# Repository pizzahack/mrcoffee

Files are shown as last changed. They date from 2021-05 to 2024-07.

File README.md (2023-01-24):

# MR. COFFEE - robotic arm

||

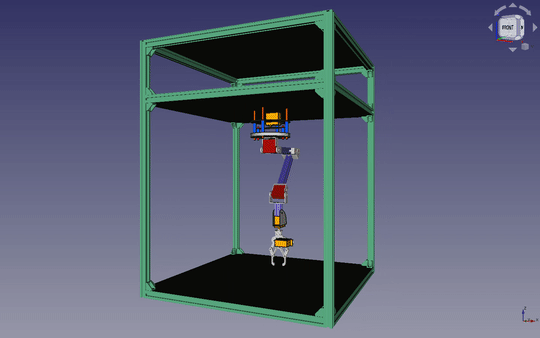
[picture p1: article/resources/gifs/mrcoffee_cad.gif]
||

## Table of contents

* [General info](#general-info)
* [Build thread on Twitter](#build-thread-on-twitter)
* [Technologies](#technologies)
* [Hardware](#hardware)
* [Build Log](#build-log)

## General info

MR. COFFEE will be a internet connected chess-playing robot. It'll allow users to play in human-machine mode (my custom UCI engine) or human-human mode, where robot serves as a remote hand for connected player. Build thread on twitter is a simple tech blog. After release of final verison of robot, I'll write an article and post full codebase. 

## Build thread on Twitter

<html lang="en">

<blockquote class="twitter-tweet"><p lang="en" dir="ltr"><a href="https://twitter.com/hashtag/robotics?src=hash&amp;ref_src=twsrc%5Etfw">#robotics</a><br>There is some sort of special feeling when you combine hardware with software and it starts to move. <a href="https://t.co/OUUlQEHs6o">pic.twitter.com/OUUlQEHs6o</a></p>&mdash; Kamil Kurach (@kamil_kurach) <a href="https://twitter.com/kamil_kurach/status/1475853391540723722?ref_src=twsrc%5Etfw">December 28, 2021</a></blockquote> <script async src="https://platform.twitter.com/widgets.js" charset="utf-8"></script>

</html>
 
## Technologies

## Hardware

## Build Log

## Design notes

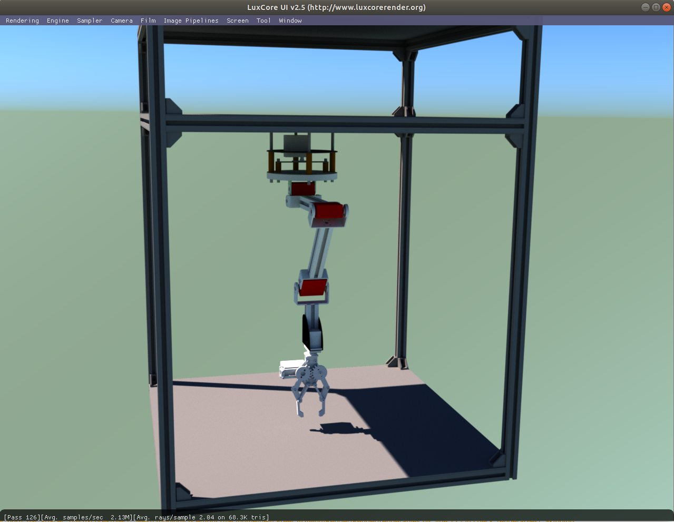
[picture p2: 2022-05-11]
mrcoffee.png

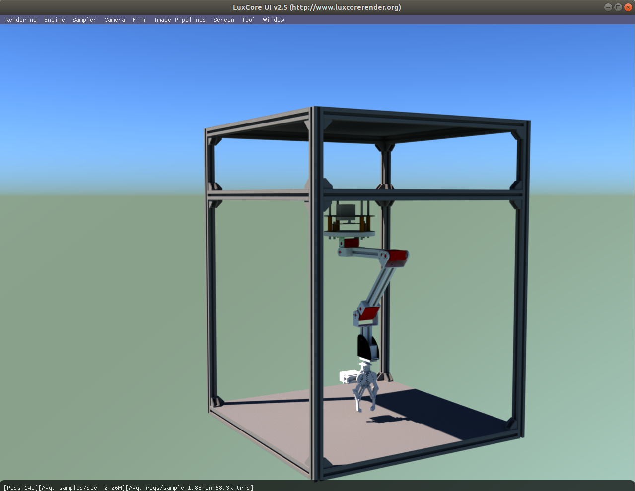
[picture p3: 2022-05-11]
mrcoffee2.png

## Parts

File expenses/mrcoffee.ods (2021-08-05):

PART_NAME | STATUS | MANUFACTURER / SUPPLIER | MANUFACTURER_PRODUCT_ID | O_PRICE | PRICE_PLN | QUANTITY | TOTAL_PLN | PART_TYPE | PART_MATERIAL | STL_FILENAME
ALU_500MM_BLACK |  | Aluxprofiel KM Engineering | 2020-BLACK | 13,68 zł |  | 10 |  | NON ELECTRONIC | ALUMINIUM
ALU_700MM_BLACK |  | Aluxprofiel KM Engineering | 2020-BLACK | 19,15 zł |  | 4 |  | NON ELECTRONIC | ALUMINIUM
ALU_600MM_SILVER |  | Aluxprofiel KM Engineering | 2020 | 13,02 zł |  | 1 |  | NON ELECTRONIC
SIDE_PLATE |  | CUSTOM |  |  |  | 2 |  | NON ELECTRONIC | METAL
FRONT_PLATE |  | CUSTOM |  |  |  | 1 |  | NON ELECTRONIC | METAL
BACK_PLATE |  | CUSTOM |  |  |  | 1 |  | NON ELECTRONIC | METAL
ELECTRIC_SOCKET |  |  |  |  |  | 1 |  | ELECTRONIC | PLASTIC/METAL
ON/OFF BUTTON |  |  |  |  |  | 1 |  | ELECTRONIC | PLASTIC/METAL
220V_CABLE |  |  |  |  |  | 1 |  | ELECTRONIC | PLASTIC/METAL
BLACK_PLEXIGLASS_TOP |  |  |  |  |  | 1 |  | NON ELECTRONIC | PLASTIC
BLACK_PLEXIGLASS_BOTTOM |  |  |  |  |  | 1 |  | NON ELECTRONIC | PLASTIC
CLEAR_PLEXIGLASS_SIDES |  |  |  |  |  | 4 |  | NON ELECTRONIC | PLASTIC
M6_BOLT |  |  |  |  |  | 32 |  | NON ELECTRONIC
M6_WASHER |  |  |  |  |  | 32 |  | NON ELECTRONIC
M6_NUT |  |  |  |  |  | 32 |  | NON ELECTRONIC
90_BRACKET |  | ABC-RC | 14416 | 2,90 zł |  | 32
M6_SLOT |  |  |  |  |  | 16
2020_ENDCAP_10_PACK |  | ABC-RC | 15877 | 3,9 |  | 1 |  | NON ELECTRONIC
SERVO_270_20KG |  | FEICHAO | F40451-270 | $13,08 |  | 3 |  | ELECTRONIC | PLASTIC/METAL
SERVO_360_11KG |  | n/a | MG996R | $5,59 |  | 1 |  | ELECTRONIC | PLASTIC/METAL
BEARING_360 |  | n/a | n/a | $8,48 |  | 1 |  | NON ELECTRONIC | ALUMINIUM
SERVO_SMALL_BRACKET |  | FEICHAO | n/a | included |  | 3 |  | NON ELECTRONIC | ALUMINIUM
SERVO_LARGE_BRACKET |  | FEICHAO | n/a | included |  | 3 |  | NON ELECTRONIC | ALUMINIUM
SERVO_METAL_DISC |  | FEICHAO | n/a | included |  | 3 |  | NON ELECTRONIC | ALUMINIUM
SERVO_METAL_DISC_W_GEAR |  | FEICHAO | n/a | included |  | 3 |  | NON ELECTRONIC | ALUMINIUM
LINK_1 |  | CUSTOM |  |  |  | 1 |  | NON ELECTRONIC | ALUMINIUM
LINK_2 |  | CUSTOM |  |  |  | 1 |  | NON ELECTRONIC | ALUMINIUM
LINK_3 |  | CUSTOM |  |  |  | 1 |  | NON ELECTRONIC | ALUMINIUM
GRIPPER_W_SERVO |  | n/a | n/a | $14,92 |  | 1 |  | NON ELECTRONIC | ALUMINIUM
FORCE_SENSOR |  | MARVELDEX | QA6P | 23,9 |  | 1 |  | ELECTRONIC | PLASTIC/METAL
GRIPPER_PADS |  | CUSTOM | CUSTOM |  |  | 2 |  | NON ELECTRONIC | SILICONE
PLASTIC_TUBE_SMALL |  |  |  |  |  |  |  | NON ELECTRONIC | PLASTIC
PLASTIC_TUBE_LARGE |  |  |  |  |  |  |  | NON ELECTRONIC | PLASTIC
RASPBERRY_PI_2_B+ |  | RASPBERRY_PI | n/a | ~120zł |  | 1 |  | ELECTRONIC
SERVO_DRIVER_HAT |  | WAVESHARE | 15275 | 42,00 zł |  | 1 |  | ELECTRONIC
POWER_SUPPLY_12V_50W |  |  |  | ~30-40zł |  | 1 |  | ELECTRONIC
VOLTAGE STABILIZER_6V |  |  |  | 10,00 zł |  | 1 |  | ELECTRONIC
VOLTAGE STABILIZER_5V |  |  |  | 10,00 zł |  | 1 |  | ELECTRONIC
VOLTAGE STABILIZER_3V |  |  |  | 10,00 zł |  | 1 |  | ELECTRONIC
RP_UPS |  |  |  |  |  | 1 |  | ELECTRONIC
LED_ARRAY_RGB |  |  |  | 10,00 zł |  | 4 |  | ELECTRONIC
RP_CAMERA |  |  |  |  |  | 1 |  | ELECTRONIC
RP_CAMERA_LONG_TAPE |  |  |  | 10,00 zł |  | 1 |  | ELECTRONIC
RP_CAMERA_HOLDER |  |  | custom 3d print? | 10-20zł |  | 1 |  | NON ELECTRONIC
LASER_CUTTING
SILICON_FOR_MOLD |  |  |  | 30zł |  | 1
LOCTITE SF 7063 |  |  |  | 30zł |  | 1
LOCTITE 243 |  |  |  | 30zł |  | 1
KAPTON TAPE |  |  |  | 30zł |  | 1
SHIPPING_TOTAL_PLN |  |  |  | 16,73 |  | n/a
USD | 3,7

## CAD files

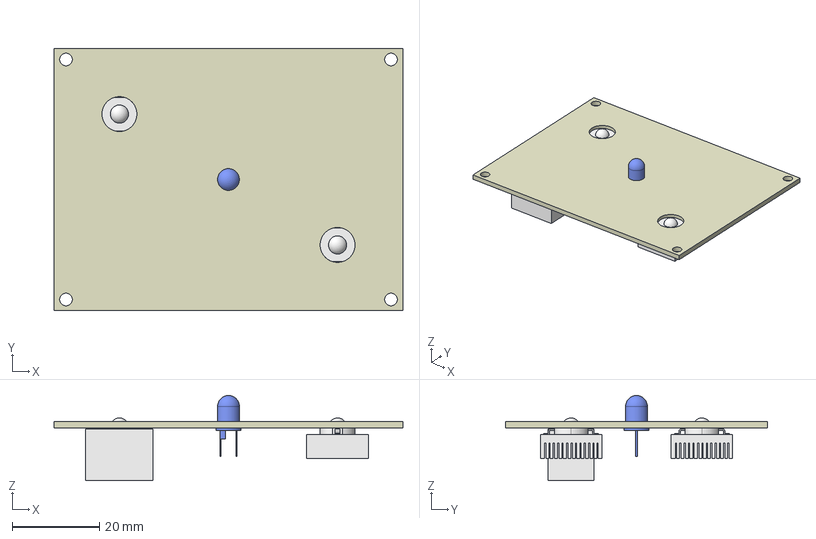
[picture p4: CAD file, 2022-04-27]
cad/pcb_assembley.FCStd
80.0 x 60.0 x 19.5 mm
PCB8060
blue_led
relay001
power_led001
power_led002
radiator001
radiator002

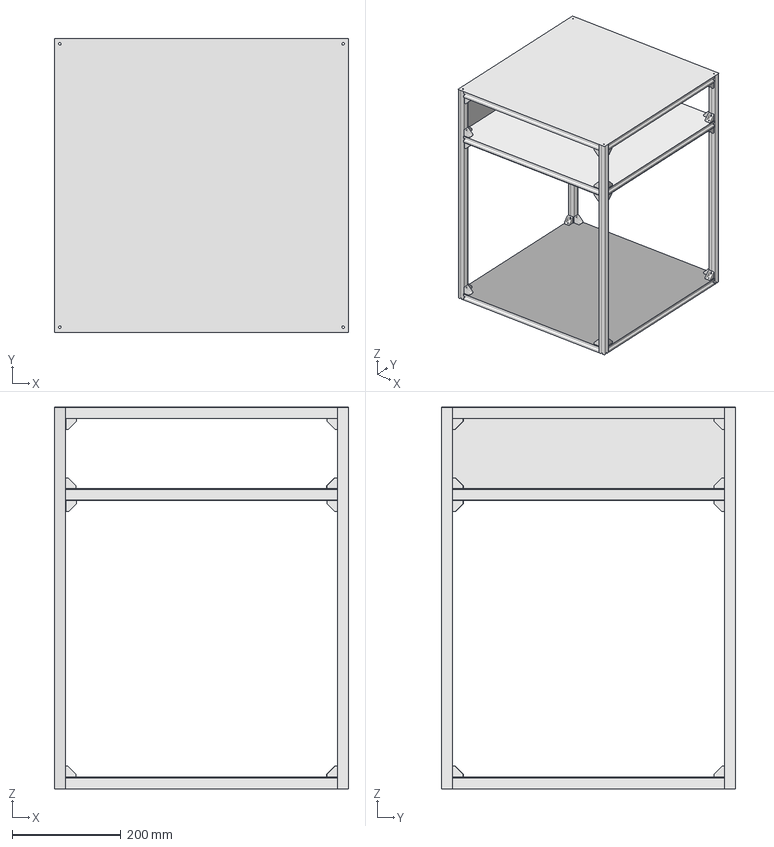
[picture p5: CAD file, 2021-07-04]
cad/assembly_v0.1.FCStd
540.0 x 540.0 x 701.0 mm
aluminium_extrusion_2020_500_bottom002
aluminium_extrusion_2020_500_bottom004
aluminium_extrusion_2020_500_middle003
aluminium_extrusion_2020_500_middle004
aluminium_extrusion_2020_500_bottom001
aluminium_extrusion_2020_500_middle001
aluminium_extrusion_2020_500_bottom003
aluminium_extrusion_2020_500_middle002
aluminium_extrusion_2020_700_side003
aluminium_extrusion_2020_700_side001
aluminium_extrusion_2020_700_side004
aluminium_extrusion_2020_700_side002
aluminium_extrusion_2020_500_top003
aluminium_extrusion_2020_500_top004
aluminium_extrusion_2020_500_top002
aluminium_extrusion_2020_500_top001
bottom_plate_500500
top_plate_500500
top_middle_plate_500500
bottom_middle_plate_500500
90_bracket_bottom002
90_bracket_bottom007
90_bracket_bottom003
90_bracket_bottom005
90_bracket_bottom006
90_bracket_bottom001
90_bracket_bottom004
90_bracket_bottom008
90_bracket_mid001
90_bracket_mid002
90_bracket_mid003
90_bracket_mid004
90_bracket_mid005
90_bracket_mid006
90_bracket_mid007
90_bracket_mid008
90_bracket_top001
90_bracket_top002
90_bracket_top003
90_bracket_top004
90_bracket_top005
90_bracket_top006
90_bracket_top007
90_bracket_top008
90_bracket_mid009
90_bracket_mid010
90_bracket_mid011
90_bracket_mid012
90_bracket_mid013
90_bracket_mid014
90_bracket_mid015
90_bracket_mid016
side_plate_500131

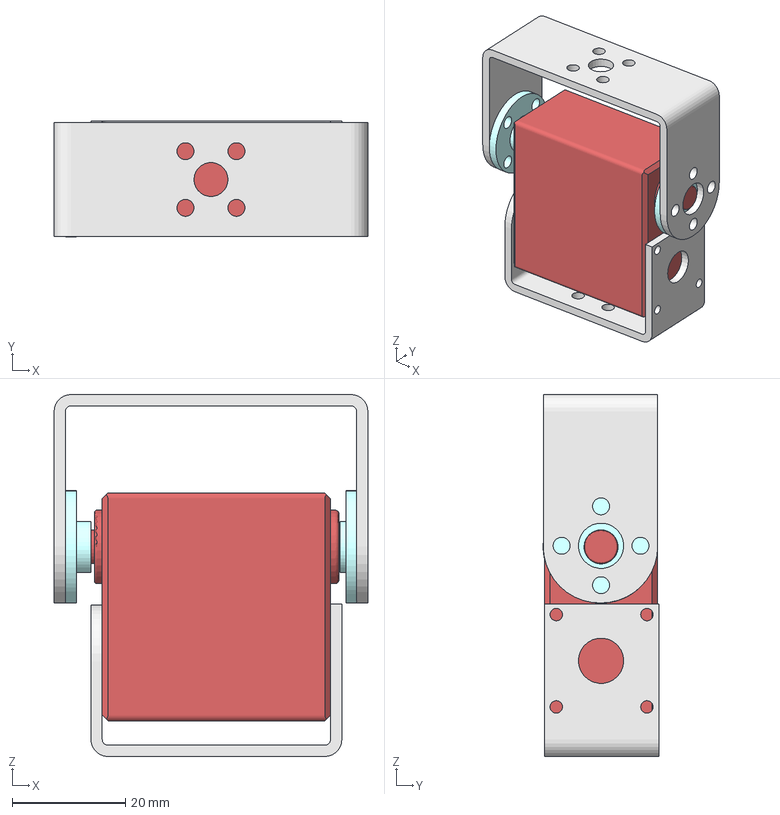
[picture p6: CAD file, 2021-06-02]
cad/servo_assembly_v0.1.FCStd
55.4 x 20.4 x 63.9 mm
large_bracket
servo_270_20
servo_metal_disc_w_gear
servo_metal_disc
small_bracket

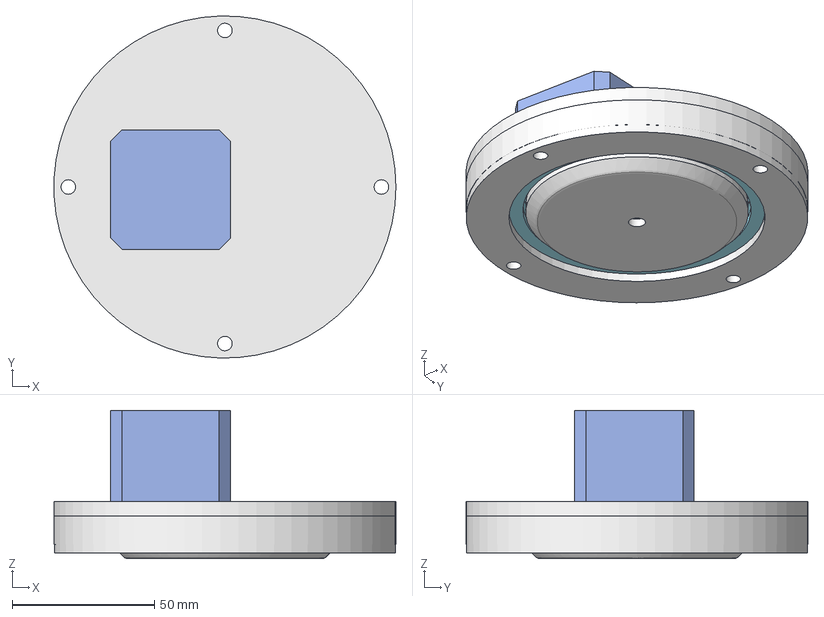
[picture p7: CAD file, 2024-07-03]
cad/test-gear-4.FCStd
120.1 x 120.2 x 52.0 mm
outer
plug_w_butterfly
bearing_holder
bottom_motor_holder
metal_ball_5mm
inner_ring_w_mount
motor_gear
stepper-motor-simplified

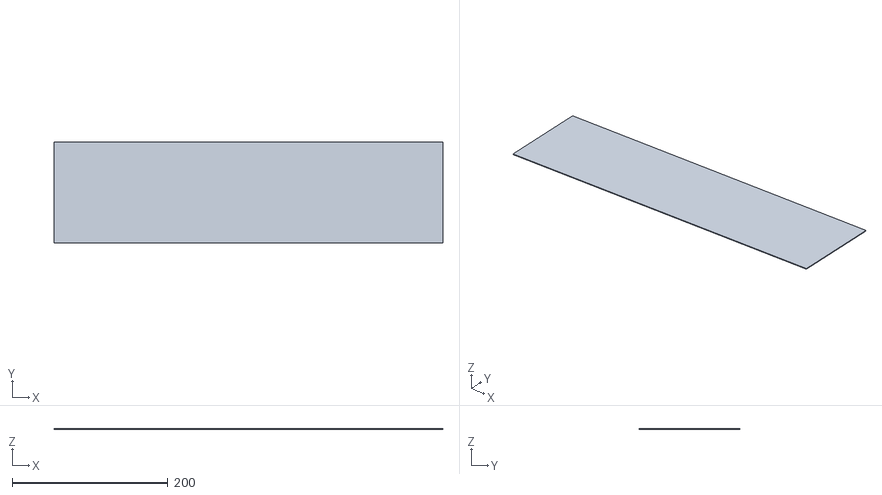
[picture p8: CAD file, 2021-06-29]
stl/side_plate_500130.stl
500.0 x 130.0 x 1.00

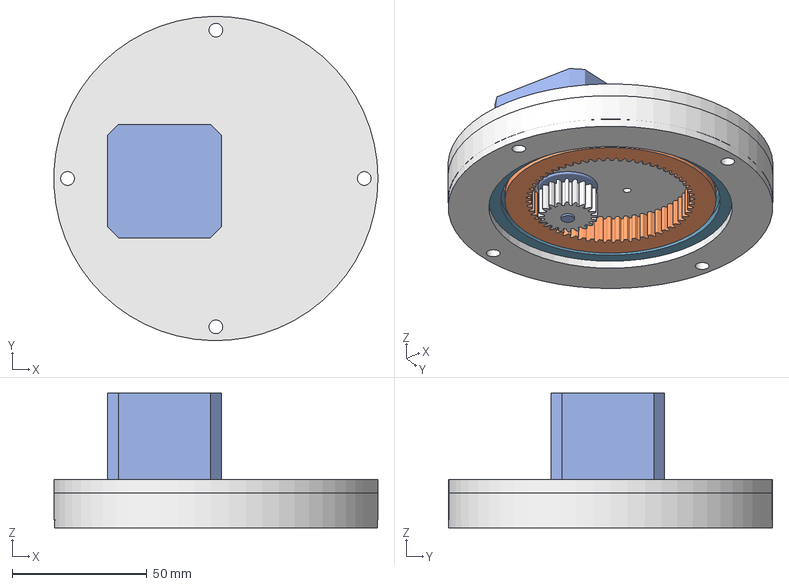
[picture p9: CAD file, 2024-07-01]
cad/test-gear-3.FCStd
120.1 x 120.2 x 50.0 mm
inner
plug
outer
plug_w_butterfly
bottom_holder
top_cover
Sfera
motor_gear
stepper-motor-Body

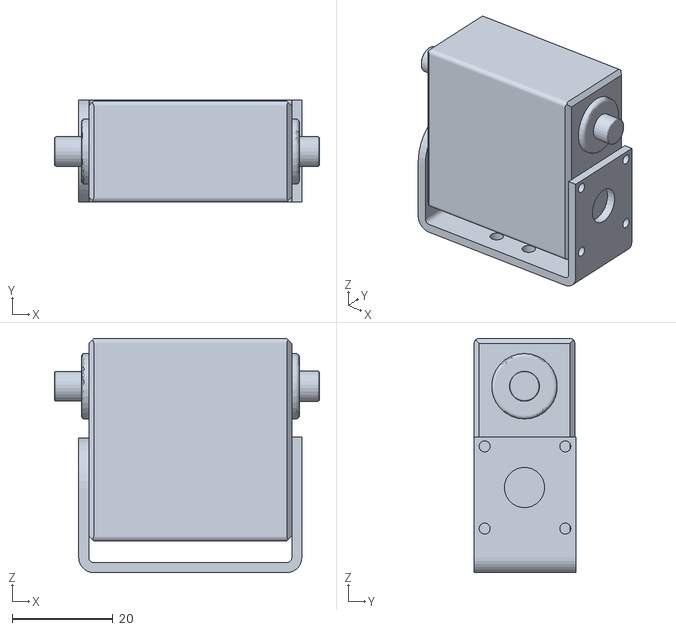
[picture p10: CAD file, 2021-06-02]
stl/servo_with_small_bracket_for_gazebo.stl
52.6 x 20.2 x 46.5

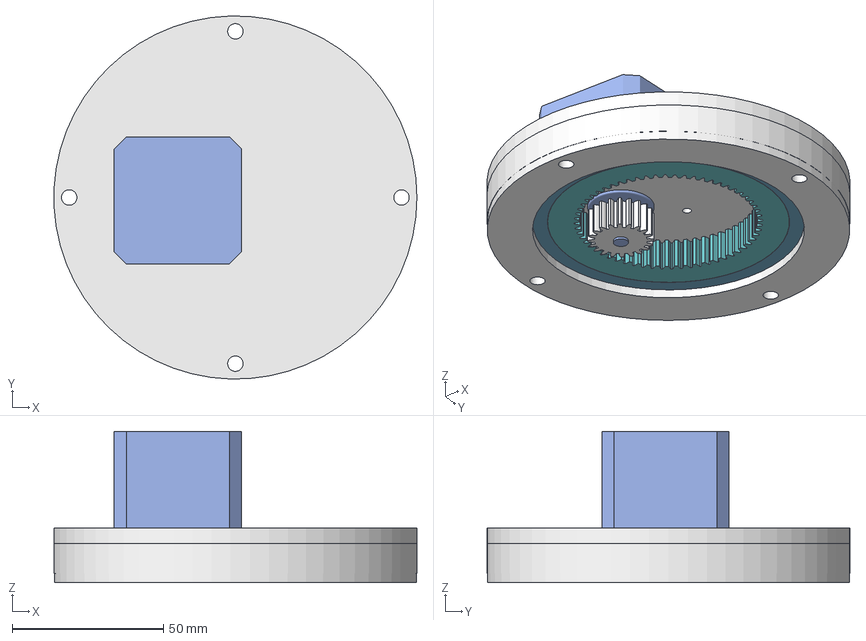
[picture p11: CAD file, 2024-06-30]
cad/test-gear-2.FCStd
120.1 x 120.2 x 50.0 mm
inner
plug
outer
bottom_holder
top_cover
motor_gear
stepper-motor-Body

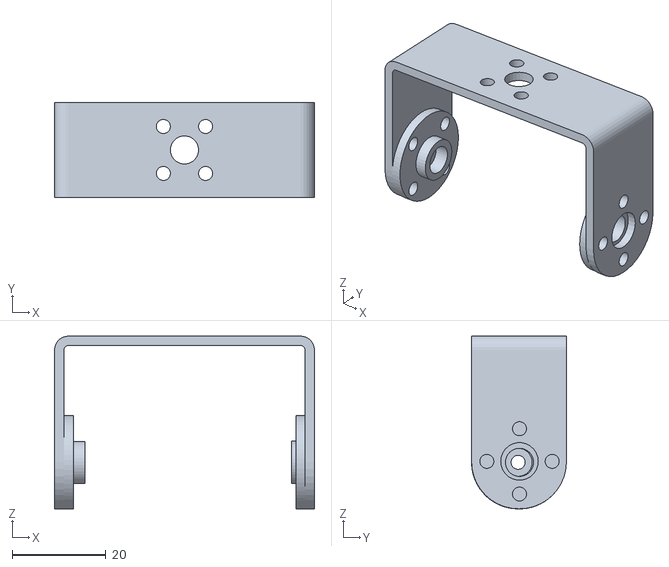
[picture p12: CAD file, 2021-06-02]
stl/large_bracket_with_discs_for_gazebo.stl
55.4 x 20.2 x 36.8

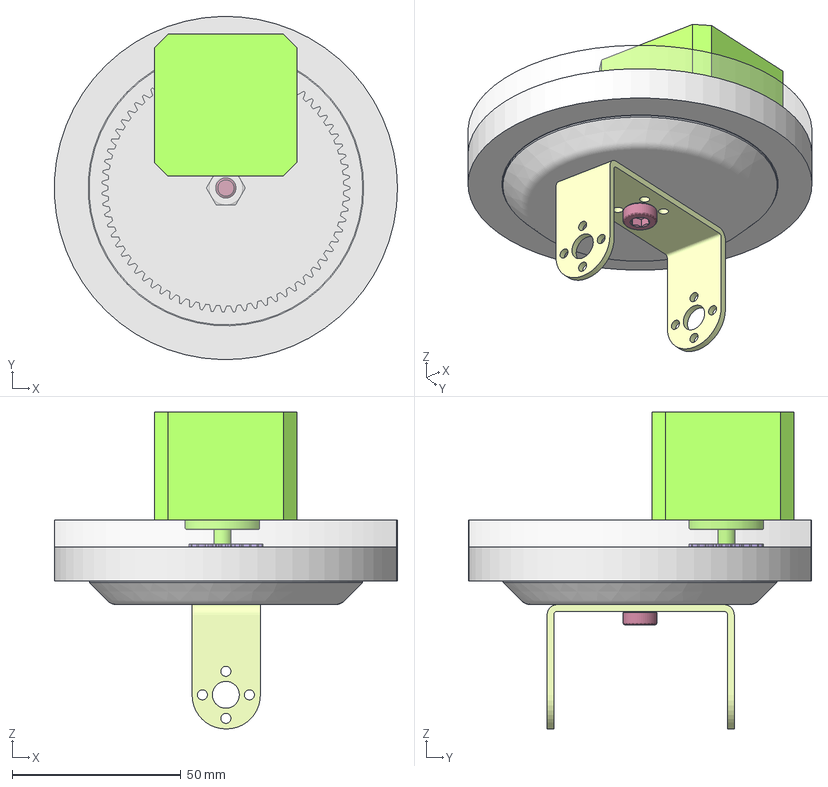
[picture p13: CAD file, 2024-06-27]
cad/concept-base-w-motor-1-petg.FCStd
101.5 x 101.6 x 93.8 mm
InternalInvoluteGear
Tube
M6x15-Śruba
M6-Nakrętka
large_bracket-large_bracket
stepper-motor-Body
motor_gear001

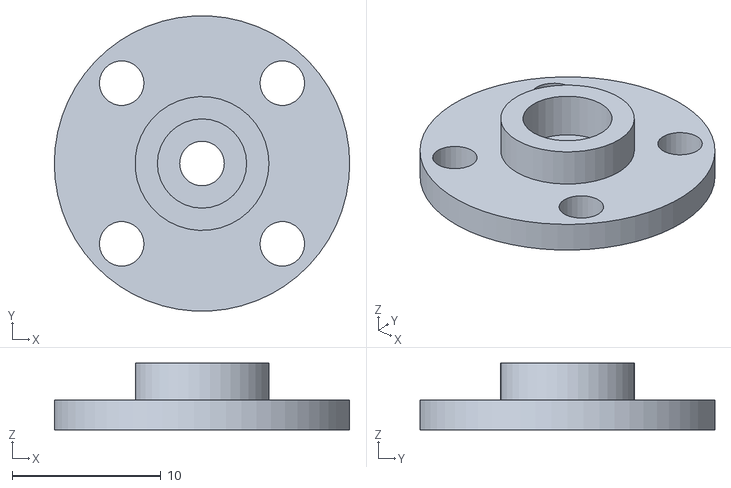
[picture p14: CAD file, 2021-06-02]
stl/servo_metal_disc_w_gear.stl
19.9 x 19.8 x 4.50

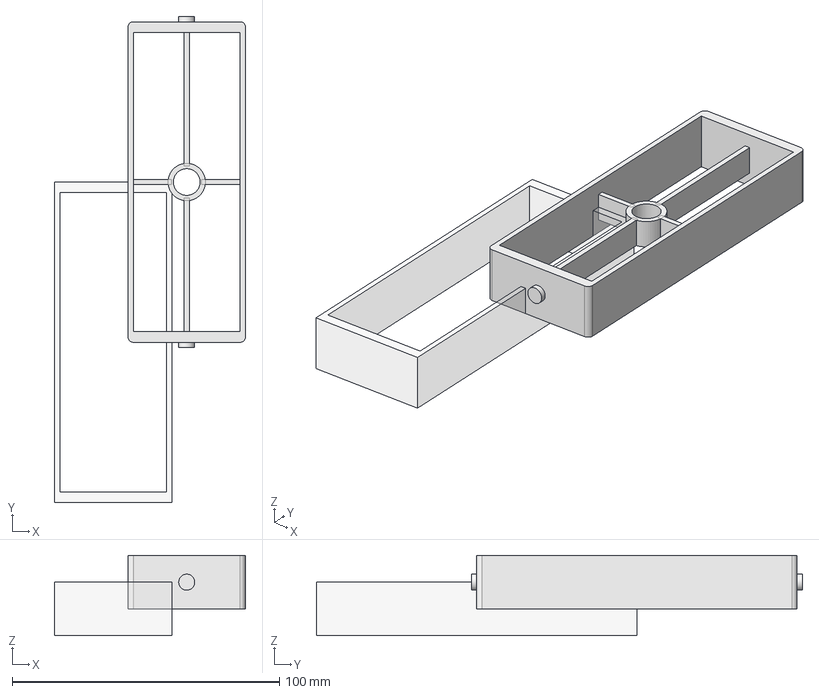
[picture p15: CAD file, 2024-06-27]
cad/test-link-2.FCStd
71.5 x 182.0 x 30.0 mm

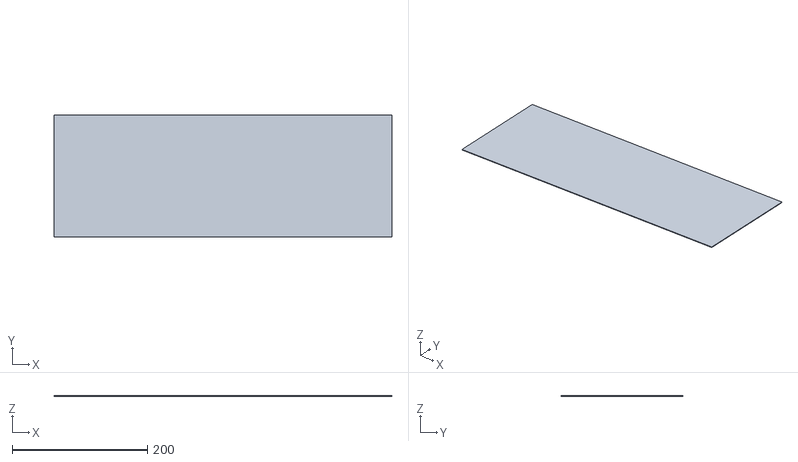
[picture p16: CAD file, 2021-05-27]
stl/front_plate_500180.stl
500.0 x 180.0 x 1.00

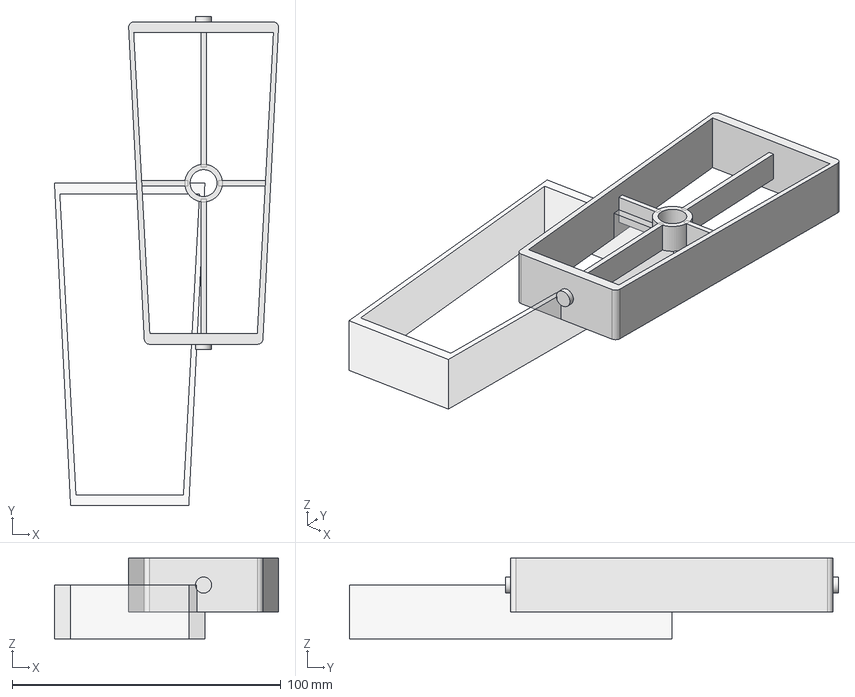
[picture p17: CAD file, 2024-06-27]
cad/test-link-1.FCStd
83.4 x 182.0 x 30.0 mm

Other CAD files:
stl/side_plate_540200.stl
cad/test-motor-gear.FCStd
cad/test-gear.FCStd
cad/base_2.0.FCStd
cad/90_bracket.FCStd
cad/aluminium_extrusion_2020.FCStd
cad/aluminium_extrusion_2020_500.FCStd
cad/aluminium_extrusion_2020_700.FCStd
cad/base_with_bearing.FCStd
cad/base_with_servo.FCStd
cad/blue_led.FCStd
cad/bottom_middle_plate_500500.FCStd
cad/bottom_plate_500500.FCStd
cad/front_plate.FCStd
cad/gripper.FCStd
cad/large_bracket.FCStd
cad/led_pcb.FCStd
cad/mrcoffee.FCStd
cad/power_led.FCStd
cad/power_supply_12V.FCStd
cad/radiator.FCStd
cad/reley.FCStd
cad/servo_270_20.FCStd
cad/servo_9g.FCStd
cad/servo_9g_horn.FCStd
cad/servo_metal_disc.FCStd
cad/servo_metal_disc_with_gear.FCStd
cad/side_plate.FCStd
cad/small_bracket.FCStd
cad/top_middle_plate_500500.FCStd
cad/top_plate_500500.FCStd
cad/wrist_servo_holder.FCStd
stl/90_bracket.stl
stl/aluminium_extrusion_2020_500.stl
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

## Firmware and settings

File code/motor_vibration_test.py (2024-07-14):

from time import sleep
import RPi.GPIO as GPIO
import random

GPIO.setwarnings(False)

DIR = 17
STEP = 27
I1 = 10
I2 = 22
MS2 = 9
MS1 = 11

GPIO.setmode(GPIO.BCM)
GPIO.setup(DIR, GPIO.OUT)
GPIO.setup(STEP, GPIO.OUT)
GPIO.setup(I1, GPIO.OUT)
GPIO.setup(I2, GPIO.OUT)
GPIO.setup(MS1, GPIO.OUT)
GPIO.setup(MS2, GPIO.OUT)

GPIO.output(I1, GPIO.LOW)
GPIO.output(I2, GPIO.LOW)

GPIO.output(MS1, GPIO.LOW)
GPIO.output(MS2, GPIO.LOW)

GPIO.output(DIR, 0)

for _ in range(4000):
  if _%2==0:
    GPIO.output(DIR, 1)
  else:
    GPIO.output(DIR, 0)
  r = random.randint(25,250)
  sleep_time = random.randint(3, 7)/1000
  for x in range(r):
    GPIO.output(STEP, GPIO.HIGH)
    sleep(sleep_time)
    GPIO.output(STEP, GPIO.LOW)
    sleep(sleep_time)
  print(_, r, sleep_time)
  sleep(random.randint(1,3))

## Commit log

2021-05-24 Add aluminium extrusion 50cm
    [aluminium_extrusion_2020_500.FCStd, aluminium_extrusion_2020_500.stl]
2021-05-24 Add aluminium extrusion 70cm
    [aluminium_extrusion_2020_700.FCStd, aluminium_extrusion_2020_700.stl]
2021-05-24 Add top plate
    [top_plate_500500.FCStd, top_plate_500500.stl]
2021-05-24 Add top middle plate
    [top_middle_plate_500500.FCStd, top_middle_plate_500500.stl]
2021-05-24 Add bottom middle plate
    [bottom_middle_plate_500500.FCStd, bottom_middle_plate_500500.stl]
2021-05-24 Add bottom plate
    [bottom_plate_500500.FCStd, bottom_plate_500500.stl]
2021-05-26 Change plate dimensions
    [bottom_middle_plate_500500.FCStd, bottom_middle_plate_500500.stl, bottom_plate_500500.FCStd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]
2021-05-26 Add side plate
    [side_plate.FCStd, side_plate_540200.stl]
2021-05-26 Add assembly v0.1
    [assembly_v0.1.FCStd]
2021-05-27 Add front plate
    [front_plate.FCStd, front_plate_500180.stl]
2021-05-30 Add large servo bracket
    [large_bracket.FCStd]
2021-05-30 Add servo disc
    [servo_metal_disc.FCStd, servo_metal_disc.stl]
2021-05-31 Add parts spreadsheet draft
    [xyz.ods]
2021-05-31 Update parts spreadsheet draft
    [xyz.ods]
2021-06-01 Add servo 270
    [servo_270_20.FCStd, servo_270_20.stl]
2021-06-02 Add servo disc with gear
    [servo_metal_disc_w_gear.stl, servo_metal_disc_with_gear.FCStd]
2021-06-02 Add M3 to bracket
    [large_bracket.FCStd]
2021-06-02 Update bracket model
    [large_bracket.stl]
2021-06-02 Add small servo bracket
    [small_bracket.FCStd, small_bracket.stl]
2021-06-02 Add aluminium extrusion base model 2020
    [aluminium_extrusion_2020.FCStd]
2021-06-02 Change M3 placement
    [small_bracket.FCStd, small_bracket.stl]
2021-06-02 Add servo assembly for gazebo model
    [servo_assembly_v0.1.FCStd]
2021-06-02 Add 3d model for gazebo urdf
    [large_bracket_with_discs_for_gazebo.stl, servo_with_small_bracket_for_gazebo.stl]
2021-06-07 Add 90 degree bracket
    [90_bracket.FCStd, 90_bracket.stl]
2021-06-07 Update model
    [assembly_v0.1.FCStd]
2021-06-29 Change side plate size
    [side_plate_500130.stl]
2021-06-29 Fix part names, add bottom brackets
    [assembly_v0.1.FCStd]
2021-07-04 Add remaining brackets
    [assembly_v0.1.FCStd]
2021-07-19 Update parts list
    [xyz.ods]
2021-07-19 Add base v0.1
    [base_with_bearing.FCStd]
2021-08-19 Move file to folder
    [xyz.ods]
2021-08-19 Move files to STL folder
    [90_bracket.stl, aluminium_extrusion_2020_500.stl, aluminium_extrusion_2020_700.stl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]
2021-08-19 Move files to FreeCAD folder
    [90_bracket.FCStd, aluminium_extrusion_2020.FCStd, aluminium_extrusion_2020_500.FCStd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]
2021-08-23 Change naming convention of folders
    [90_bracket.FCStd, 90_bracket.stl, aluminium_extrusion_2020.FCStd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]
2021-08-30 Add power led model
    [power_led.FCStd]
2021-08-30 Add led model
    [blue_led.FCStd]
2021-08-30 Add pcb model
    [led_pcb.FCStd]
2021-08-31 Change led length
    [blue_led.FCStd]
2021-08-31 Add relay model
    [reley.FCStd]
2021-09-03 Add radiator model
    [radiator.FCStd]
2021-09-03 Add power supply simple model
    [power_supply_12V.FCStd]
2021-09-16 Add 9g servo model
    [servo_9g.FCStd, servo_9g_horn.FCStd]
2021-12-14 Rename file
    [mrcoffee.ods]
2021-12-14 Add led pcb v0.1
    [pcb_assembley.FCStd, pcb_assembley.stl]
2021-12-29 Add base model with mg996r servo
    [base_with_servo.FCStd]
2021-12-29 Add v0.1 minimal model for simulator (base, shoulder)
    [mrcoffee.FCStd]
2021-12-31 Add full arm without gripper (different lengths of links)
    [mrcoffee.FCStd]
2022-01-12 Add gripper idea
    [gripper.FCStd]
2022-01-13 Add improved design
    [gripper.FCStd]
2022-01-13 Add gripper design v1.0
    [gripper.FCStd]
2022-01-14 Reverse model
    [gripper.FCStd]
2022-04-25 Add wrist servo holder v2
    [wrist_servo_holder.FCStd]
2022-04-27 Update models
    [mrcoffee.FCStd, pcb_assembley.FCStd, wrist_servo_holder.FCStd]
2022-04-28 Model cleanup (remove gripper, replace mg996r servos)
    [mrcoffee.FCStd]
2022-04-28 Add servo body
    [wrist_servo_holder.FCStd]
2022-05-11 Add ots gripper
    [mrcoffee.FCStd]
2023-05-12 Add base 2.0 initial design based on reprap 3d printer parts
    [base_2.0.FCStd]
2024-06-23 Add test gears for base
    [test-gear.FCStd, test-motor-gear.FCStd]
2024-06-27 Add test links (PETG)
    [test-link-1.FCStd, test-link-2.FCStd]
2024-06-27 Add concept base with printed bearing and integrated motor
    [concept-base-w-motor-1-petg.FCStd]
2024-06-30 Add test base and bearing model with motor holder
    or 3d printing + 5mm metal balls
    [test-gear-2.FCStd]
2024-07-01 Add test gear with smaller inner ring (by 1mm)
    [test-gear-3.FCStd]
2024-07-03 Add test gear with integrated mount plate
    [test-gear-4.FCStd]
2024-07-14 Add stepper motor vibration test script
    [motor_vibration_test.py]
